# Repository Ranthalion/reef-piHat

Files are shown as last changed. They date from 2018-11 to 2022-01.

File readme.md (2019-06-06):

View this project on [CADLAB.io](https://cadlab.io/project/1832). 

# reef-piHat
RPI Hat for reef-pi

Supports
 - Back powering the rpi with 5v
 - 9 channels of PWM control via PCA9685 (split between 3 connectors)
 - 3 channels for 1 wire communication (up to 3 DS18B20 temperature probes)
 - 2 i2c ports for ph probe modules
 - 2 ATO sensors
 - 8 channel 12v relay control via ULN2803
 - 8 GPIO breakout (intended for 3.3v relay module)

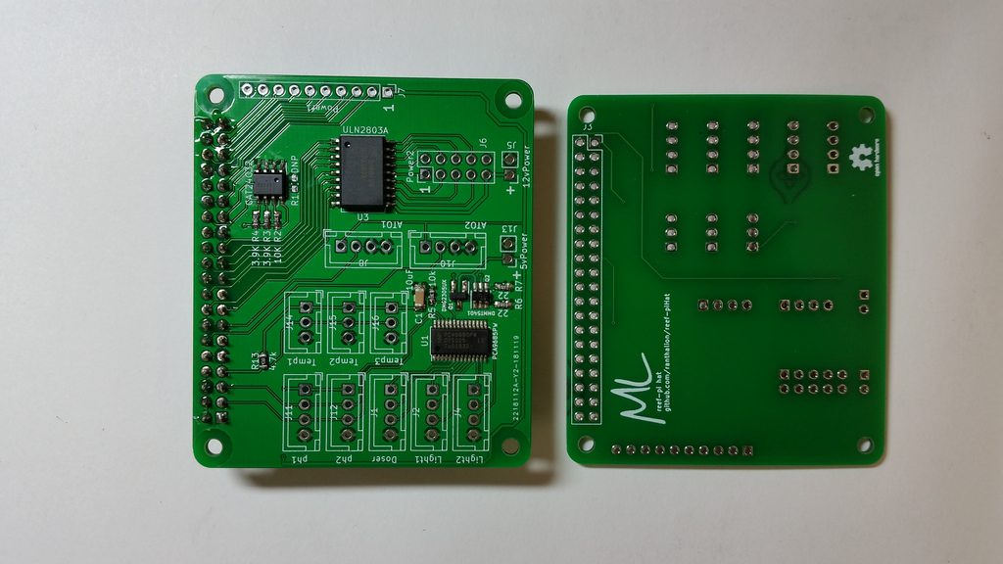
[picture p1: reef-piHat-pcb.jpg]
Board


Schematic

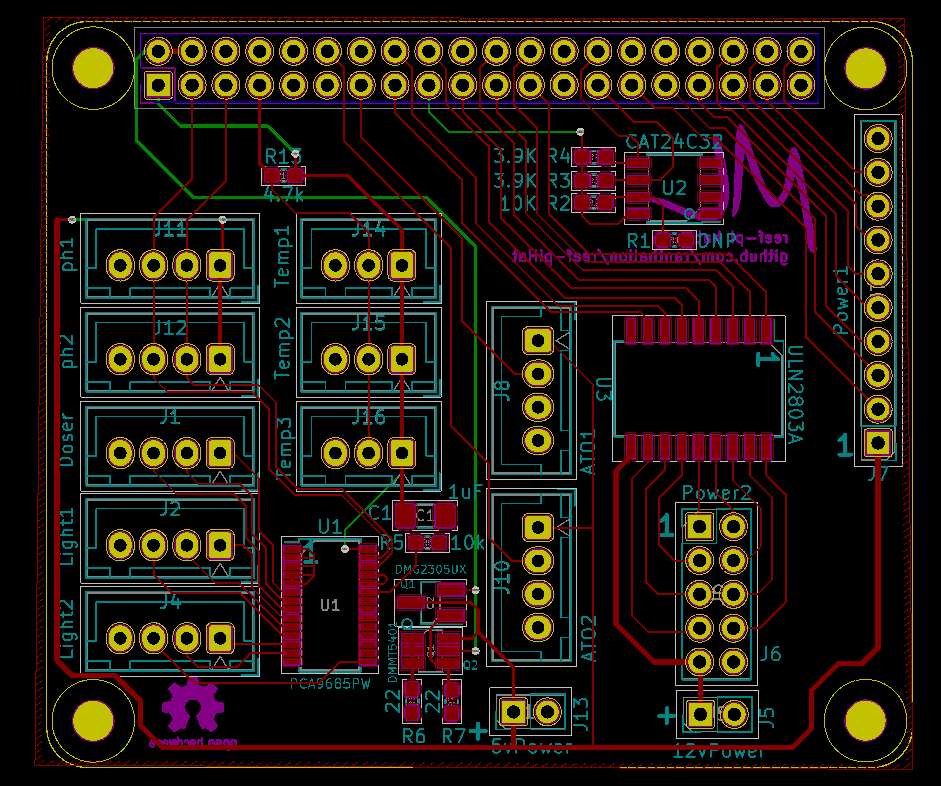
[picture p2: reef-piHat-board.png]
Layout




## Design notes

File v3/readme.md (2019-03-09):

# reef-piHat
RPI Hat for reef-pi

Supports
 - Back powering the rpi with 5v
 - 12 channels of PWM control via PCA9685 (split between 4 connectors) with address selection
 - 3 channels for 1 wire communication (up to 3 DS18B20 temperature probes)
 - 2 i2c ports for ph probe modules
 - 2 ATO sensors with input protection
 - 8 channel 12v relay control via ULN2803
 - 8 GPIO breakout with input and output protection

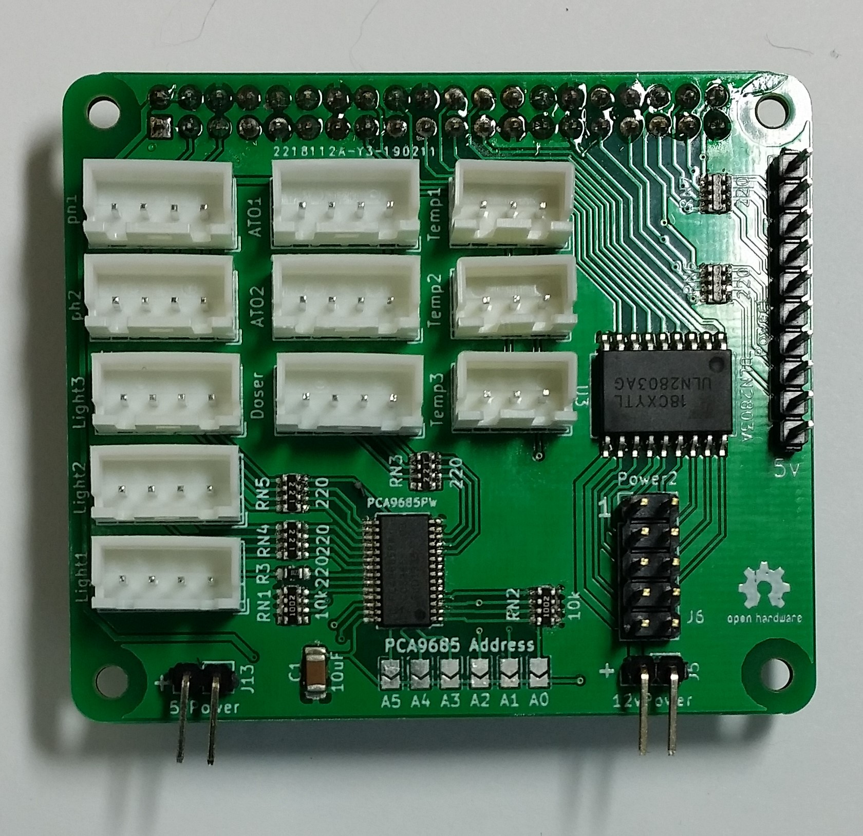
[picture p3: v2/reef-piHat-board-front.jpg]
Board front


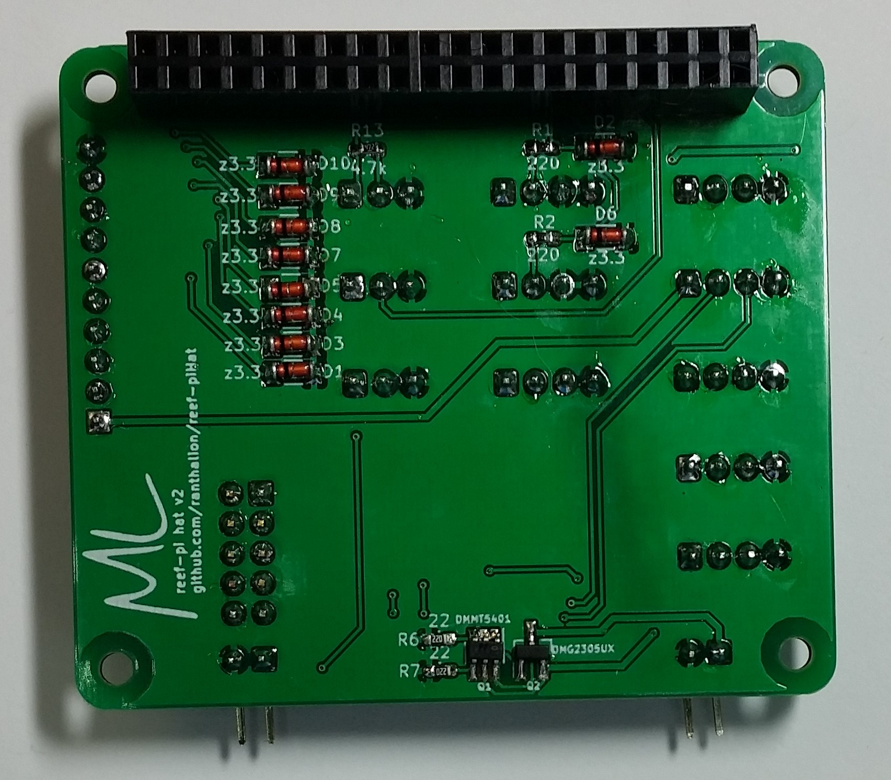
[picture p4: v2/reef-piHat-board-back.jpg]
Board back


Schematic

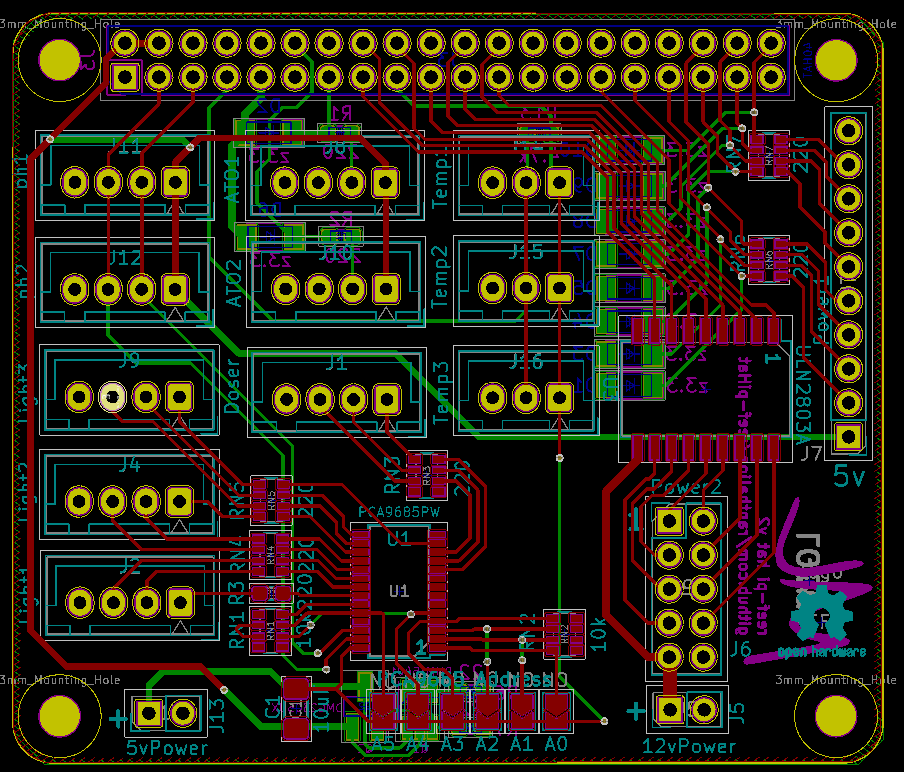
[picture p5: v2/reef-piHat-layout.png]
Layout




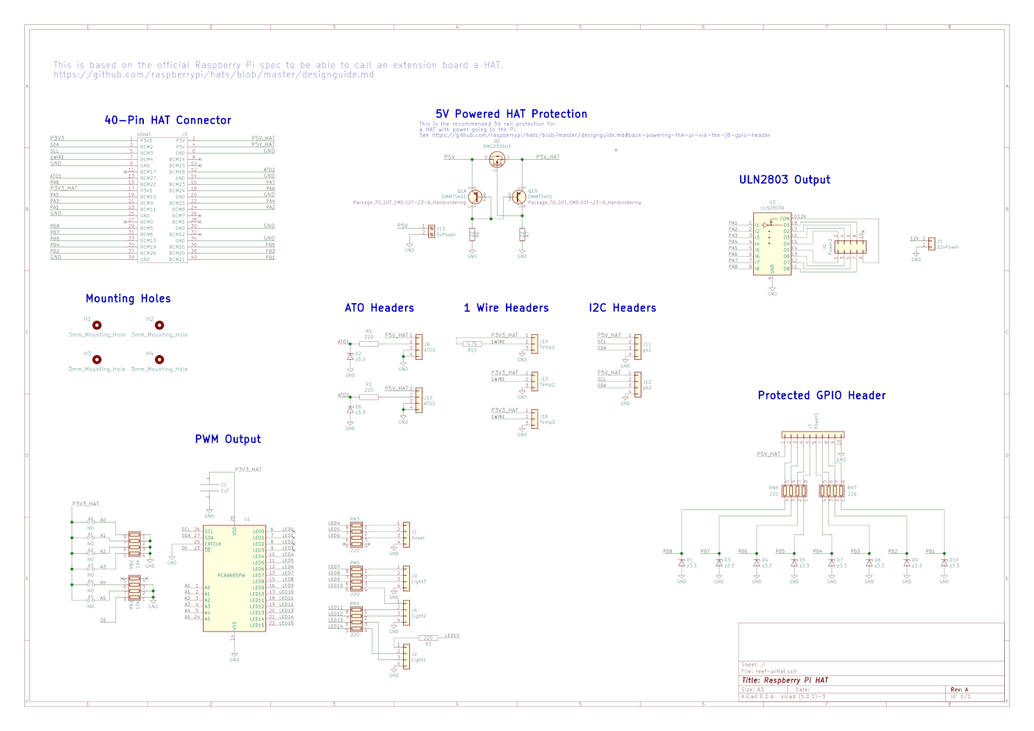
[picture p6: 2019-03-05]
v3/reef-piHat-schematic.png

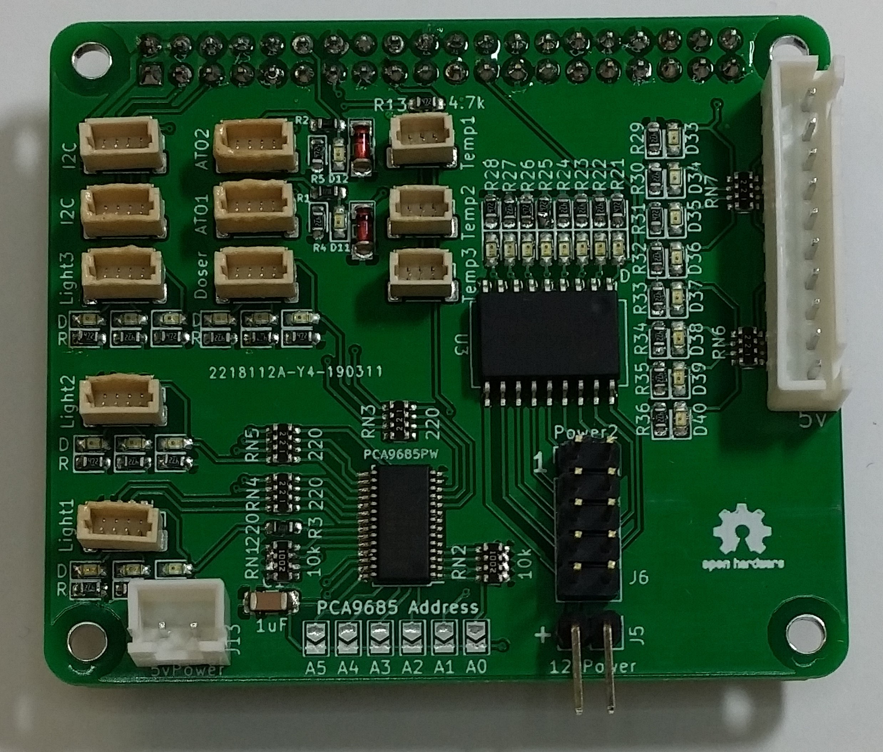
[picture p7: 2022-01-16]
v3/front.jpg

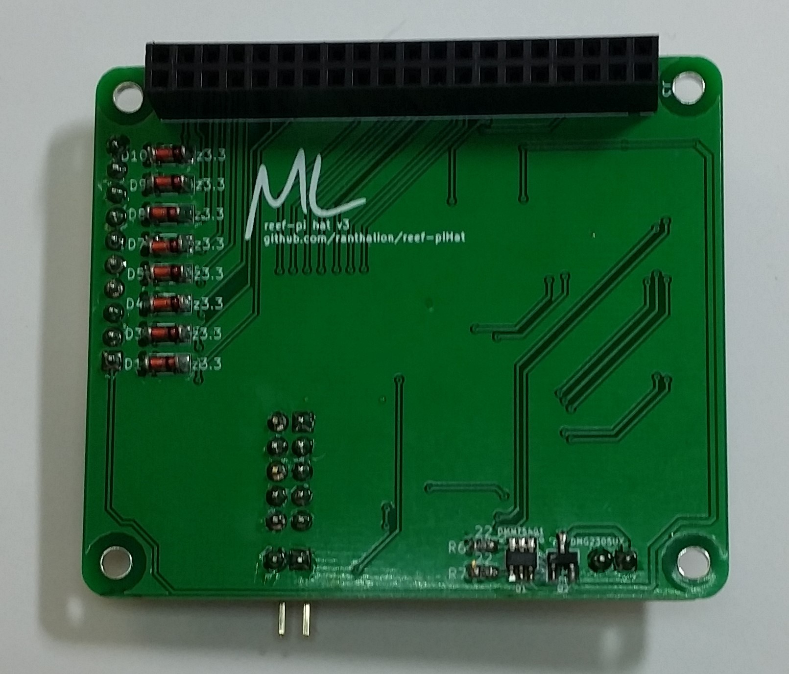
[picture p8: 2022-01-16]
v3/back.jpg

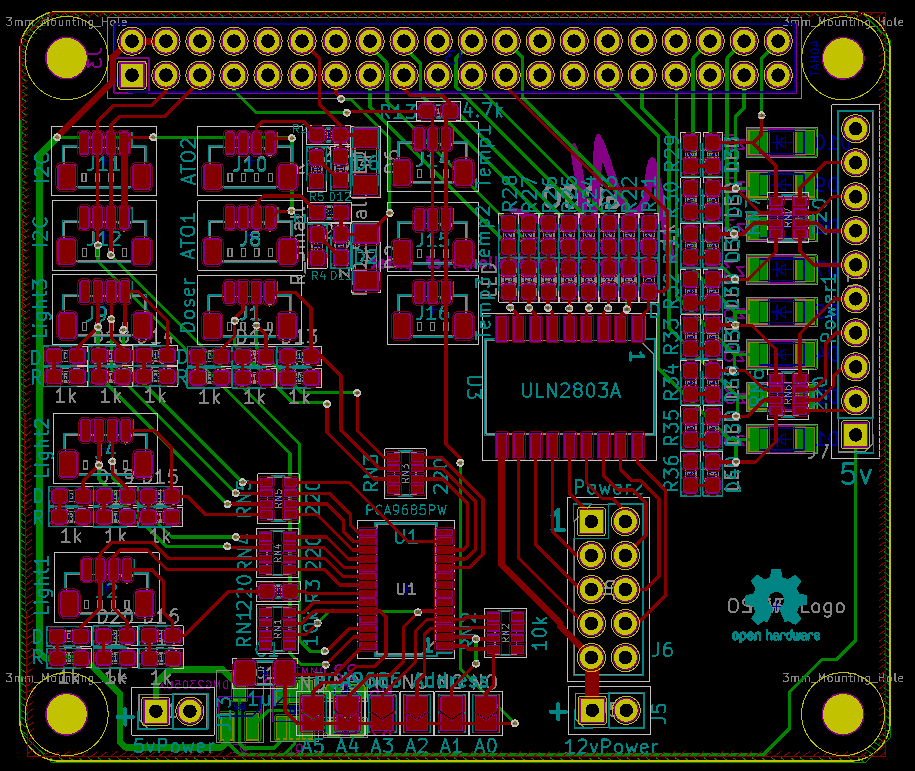
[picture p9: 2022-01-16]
v3/reef-piHat-board.png

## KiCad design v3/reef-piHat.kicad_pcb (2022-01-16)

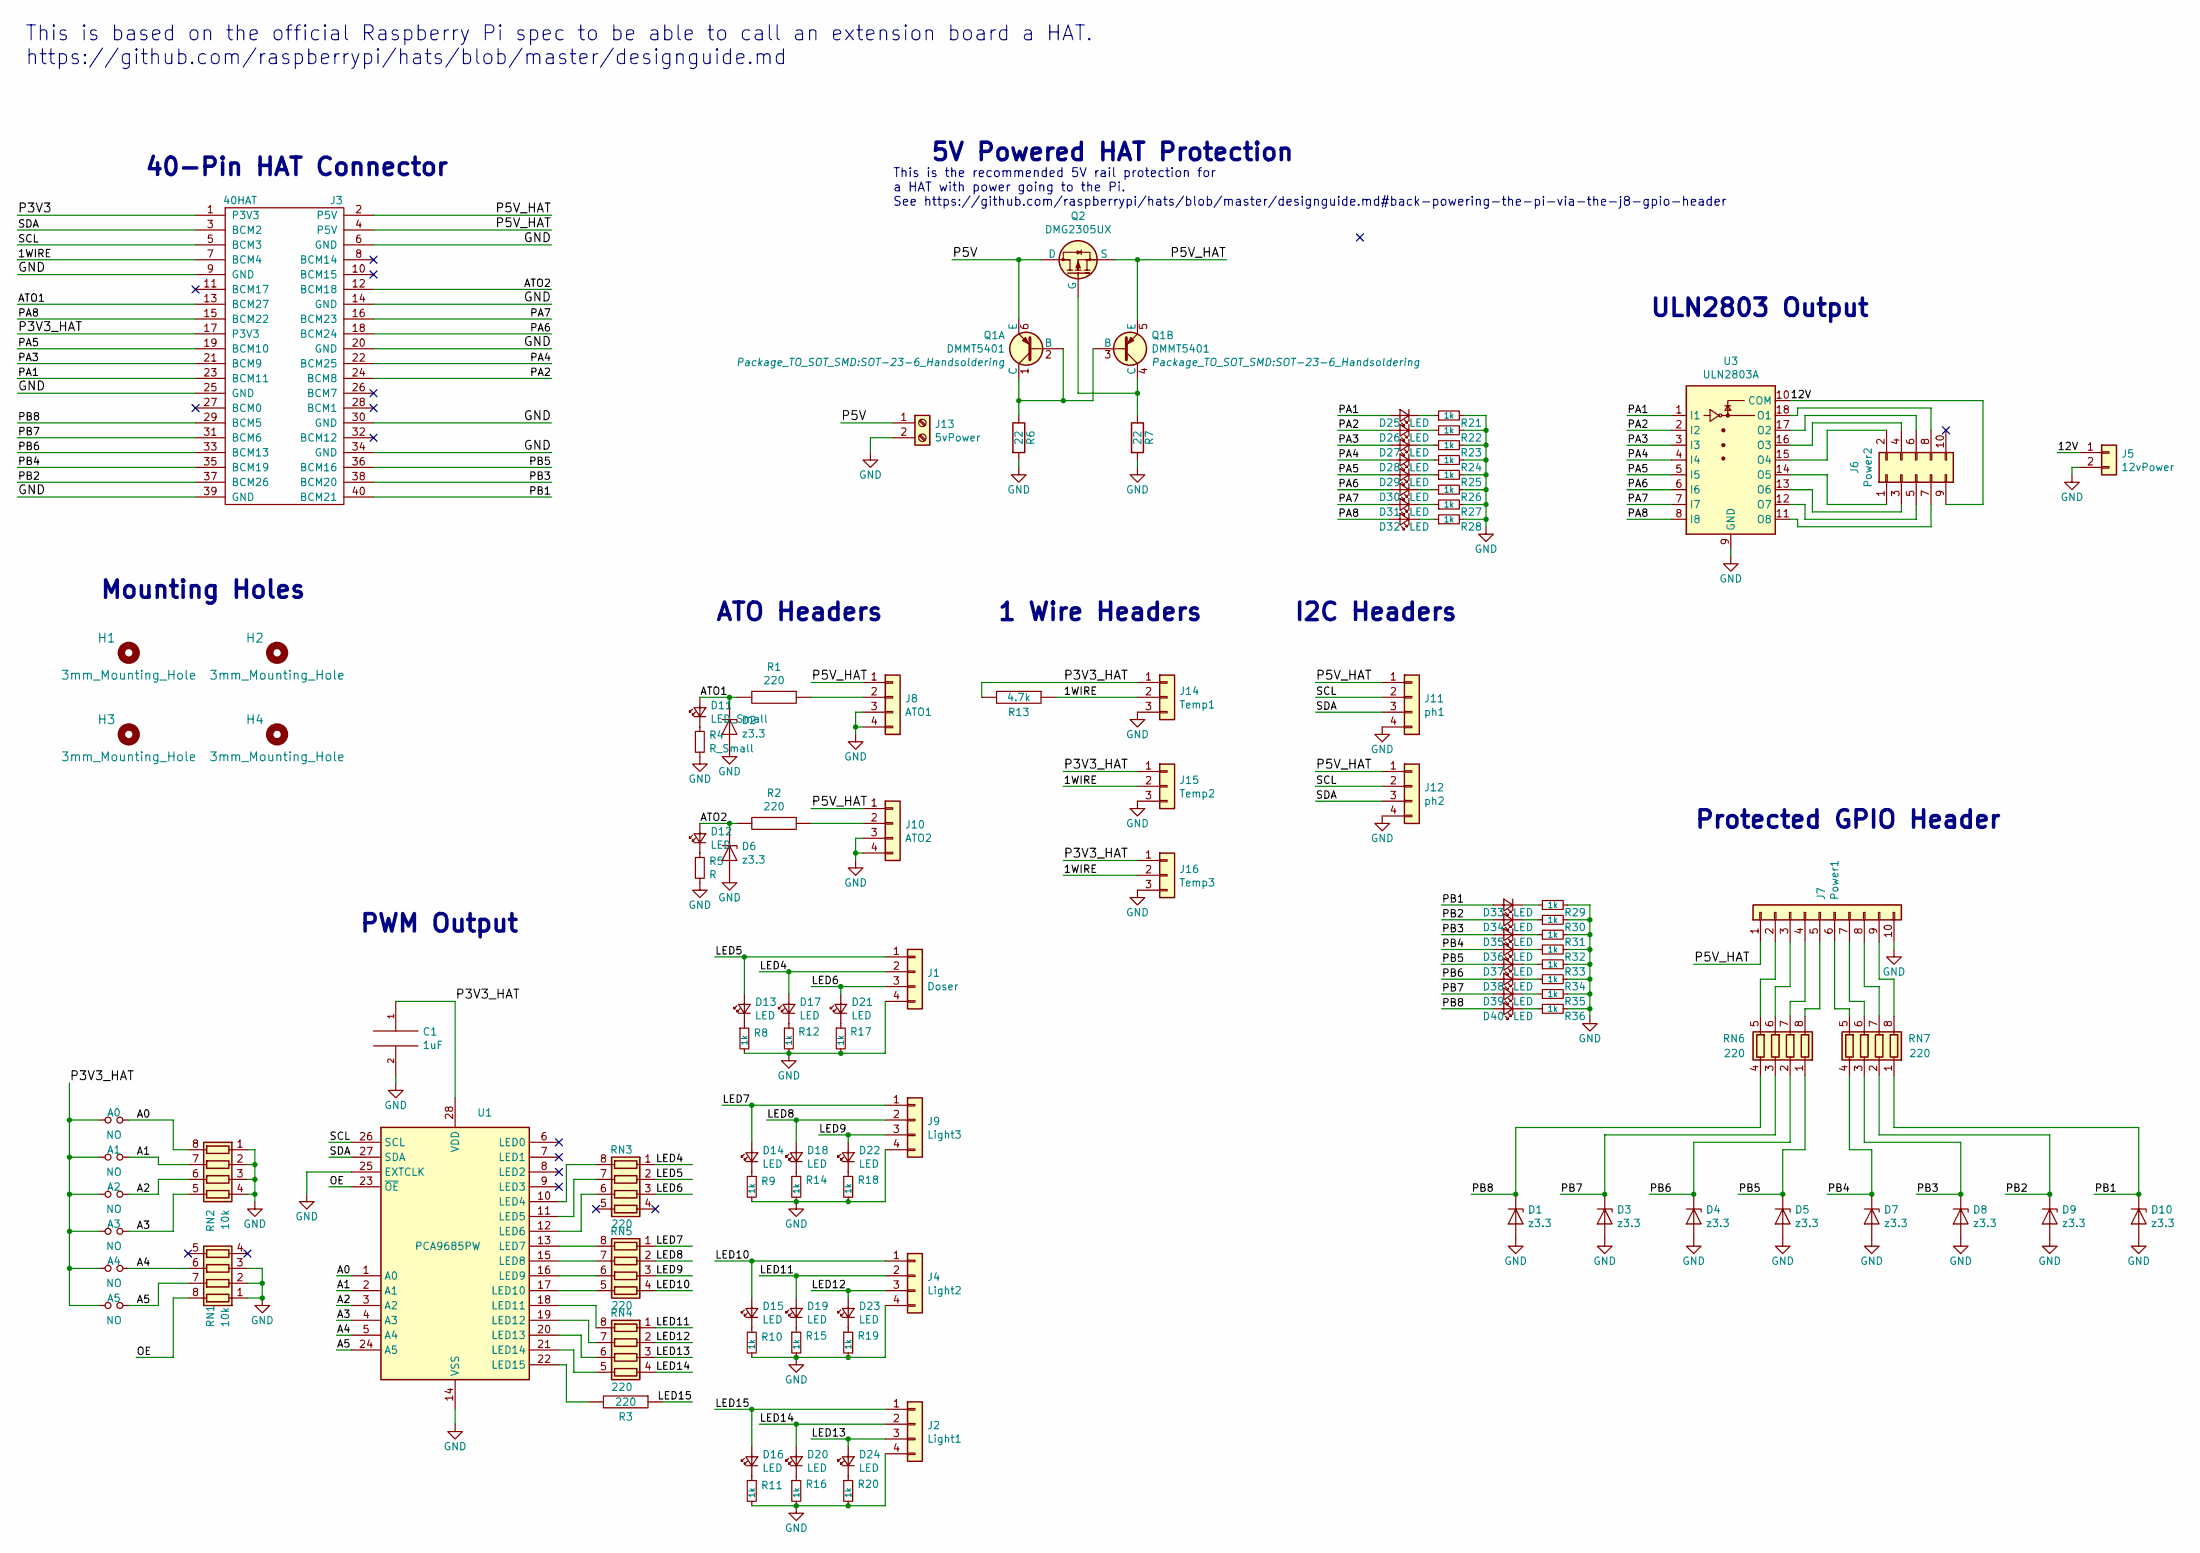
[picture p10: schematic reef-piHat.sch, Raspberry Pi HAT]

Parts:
A0, A1, A2, A3, A4, A5: NO; SolderJumper-2_P1.3mm_Open_TrianglePad1.0x1.5mm
C1: 1uF; C_1206_3216Metric_Pad1.42x1.75mm_HandSolder
D1, D2, D3, D4, D5, D6, D7, D8, D9, D10: z3.3; D_MiniMELF
D11: LED_Small; LED_0603_1608Metric_Pad1.05x0.95mm_HandSolder
D12, D13, D14, D15, D16, D17, D18, D19, D20, D21, D22, D23, D24, D25, D26, D27, D28, D29, D30, D31, D32, D33, D34, D35, D36, D37, D38, D39, D40: LED; LED_0603_1608Metric_Pad1.05x0.95mm_HandSolder
H1, H2, H3, H4: 3mm_Mounting_Hole; NPTH_3mm_ID
J1: Doser; JST_SH_BM04B-SRSS-TB_1x04-1MP_P1.00mm_Vertical
J2: Light1; JST_SH_BM04B-SRSS-TB_1x04-1MP_P1.00mm_Vertical
J3: 40HAT; PinSocket_2x20_P2.54mm_Vertical
J4: Light2; JST_SH_BM04B-SRSS-TB_1x04-1MP_P1.00mm_Vertical
J5: 12vPower; PinHeader_1x02_P2.54mm_Vertical
J6: Power2; PinHeader_2x05_P2.54mm_Vertical
J7: Power1; PinHeader_1x10_P2.54mm_Vertical
J8: ATO1; JST_SH_BM04B-SRSS-TB_1x04-1MP_P1.00mm_Vertical
J9: Light3; JST_SH_BM04B-SRSS-TB_1x04-1MP_P1.00mm_Vertical
J10: ATO2; JST_SH_BM04B-SRSS-TB_1x04-1MP_P1.00mm_Vertical
J11: ph1; JST_SH_BM04B-SRSS-TB_1x04-1MP_P1.00mm_Vertical
J12: ph2; JST_SH_BM04B-SRSS-TB_1x04-1MP_P1.00mm_Vertical
J13: 5vPower; PinHeader_1x02_P2.54mm_Vertical
J14: Temp1; JST_SH_BM03B-SRSS-TB_1x03-1MP_P1.00mm_Vertical
J15: Temp2; JST_SH_BM03B-SRSS-TB_1x03-1MP_P1.00mm_Vertical
J16: Temp3; JST_SH_BM03B-SRSS-TB_1x03-1MP_P1.00mm_Vertical
Q1: DMMT5401; SOT-23-6_Handsoldering
Q2: DMG2305UX; SOT-23_Handsoldering
R1, R2, R3: 220; R_0603_1608Metric_Pad1.05x0.95mm_HandSolder
R4: R_Small; LED_0603_1608Metric_Pad1.05x0.95mm_HandSolder
R5: R; LED_0603_1608Metric_Pad1.05x0.95mm_HandSolder
R6, R7: 22; R_0603_1608Metric_Pad1.05x0.95mm_HandSolder; MPN RC0402JR-0722RL
R8, R9, R10, R11, R12, R14, R15, R16, R17, R18, R19, R20, R21, R22, R23, R24, R25, R26, R27, R28, R29, R30, R31, R32, R33, R34, R35, R36: 1k; LED_0603_1608Metric_Pad1.05x0.95mm_HandSolder
R13: 4.7k; R_0603_1608Metric_Pad1.05x0.95mm_HandSolder
RN1, RN2: 10k; R_Array_Convex_4x0603
RN3, RN4, RN5, RN6, RN7: 220; R_Array_Convex_4x0603
U1: PCA9685PW; TSSOP-28_4.4x9.7mm_P0.65mm
U3: ULN2803A; SOP-18_7.0x12.5mm_P1.27mm

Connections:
/1WIRE: J3.7 (BCM4), J14.2, J15.2, J16.2, R13.1
/12V: J5.1, J6.9, U3.10 (COM)
/A0: A0.1, RN2.8 (R1.2), U1.1 (A0)
/A1: A1.1, RN2.7 (R2.2), U1.2 (A1)
/A2: A2.1, RN2.6 (R3.2), U1.3 (A2)
/A3: A3.1, RN2.5 (R4.2), U1.4 (A3)
/A4: A4.1, RN1.6 (R3.2), U1.5 (A4)
/A5: A5.1, RN1.7 (R2.2), U1.24 (A5)
/ATO1: D2.1 (K), D11.2 (A), J3.13 (BCM27), R1.2
/ATO2: D6.1 (K), D12.2 (A), J3.12 (BCM18), R2.2
/LED4: D17.2 (A), J1.2, RN3.1 (R1.1)
/LED5: D13.2 (A), J1.1, RN3.2 (R2.1)
/LED6: D21.2 (A), J1.3, RN3.3 (R3.1); also elsewhere on the board
/LED7: D14.2 (A), J9.1, RN5.1 (R1.1)
/LED8: D18.2 (A), J9.2, RN5.2 (R2.1)
/LED9: D22.2 (A), J9.3, RN5.3 (R3.1); also elsewhere on the board
/LED10: D15.2 (A), J4.1, RN5.4 (R4.1)
/LED11: D19.2 (A), J4.2, RN4.1 (R1.1)
/LED12: D23.2 (A), J4.3, RN4.2 (R2.1); also elsewhere on the board
/LED13: D24.2 (A), J2.3, RN4.3 (R3.1); also elsewhere on the board
/LED14: D20.2 (A), J2.2, RN4.4 (R4.1)
/LED15: D16.2 (A), J2.1, R3.1
/OE: RN1.8 (R1.2), U1.23 (~OE)
/P3V3: J3.1 (P3V3)
/P3V3_HAT: A0.2, A1.2, A2.2, A3.2, A4.2, A5.2, C1.1, J3.17 (P3V3), J14.1, J15.1, J16.1, R13.2, U1.28 (VDD)
/P5V: J13.1, Q1.6 (E), Q2.3 (D)
/P5V_HAT: J3.2 (P5V), J3.4 (P5V), J7.1, J8.1, J10.1, J11.1, J12.1, Q1.5 (E), Q2.2 (S)
/PA1: D25.2 (A), J3.23 (BCM11), U3.1 (I1); also elsewhere on the board
/PA2: D26.2 (A), J3.24 (BCM8), U3.2 (I2)
/PA3: D27.2 (A), J3.21 (BCM9), U3.3 (I3)
/PA4: D28.2 (A), J3.22 (BCM25), U3.4 (I4)
/PA5: D29.2 (A), J3.19 (BCM10), U3.5 (I5)
/PA6: D30.2 (A), J3.18 (BCM24), U3.6 (I6)
/PA7: D31.2 (A), J3.16 (BCM23), U3.7 (I7)
/PA8: D32.2 (A), J3.15 (BCM22), U3.8 (I8)
/PB1: D10.1 (K), D33.2 (A), J3.40 (BCM21), RN7.1 (R1.1)
/PB2: D9.1 (K), D34.2 (A), J3.37 (BCM26), RN7.2 (R2.1)
/PB3: D8.1 (K), D35.2 (A), J3.38 (BCM20), RN7.3 (R3.1)
/PB4: D7.1 (K), D36.2 (A), J3.35 (BCM19), RN7.4 (R4.1)
/PB5: D5.1 (K), D37.2 (A), J3.36 (BCM16), RN6.1 (R1.1)
/PB6: D4.1 (K), D38.2 (A), J3.33 (BCM13), RN6.2 (R2.1)
/PB7: D3.1 (K), D39.2 (A), J3.31 (BCM6), RN6.3 (R3.1)
/PB8: D1.1 (K), D40.2 (A), J3.29 (BCM5), RN6.4 (R4.1)
/SCL: J3.5 (BCM3), J11.2, J12.2, U1.26 (SCL)
/SDA: J3.3 (BCM2), J11.3, J12.3, U1.27 (SDA)
GND: C1.2, D1.2 (A), D2.2 (A), D3.2 (A), D4.2 (A), D5.2 (A), D6.2 (A), D7.2 (A), D8.2 (A), D9.2 (A), D10.2 (A), J1.4, J2.4, J3.6 (GND), J3.9 (GND), J3.14 (GND), J3.20 (GND), J3.25 (GND), J3.30 (GND), J3.34 (GND), J3.39 (GND), J4.4, J5.2, J7.10, J8.3, J8.4, J9.4, J10.3, J10.4, J11.4, J12.4, J13.2, J14.3, J15.3, J16.3, R4.2, R5.2, R6.2, R7.2, R8.2, R9.2, R10.2, R11.2, R12.2, R14.2, R15.2, R16.2, R17.2, R18.2, R19.2, R20.2, R21.2, R22.2, R23.2, R24.2, R25.2, R26.2, R27.2, R28.2, R29.2, R30.2, R31.2, R32.2, R33.2, R34.2, R35.2, R36.2, RN1.1 (R1.1), RN1.2 (R2.1), RN1.3 (R3.1), RN2.1 (R1.1), RN2.2 (R2.1), RN2.3 (R3.1), RN2.4 (R4.1), U1.14 (VSS), U1.25 (EXTCLK), U3.9 (GND); also elsewhere on the board
unnamed: D11.1 (K), R4.1
unnamed: D12.1 (K), R5.1
unnamed: D13.1 (K), R8.1
unnamed: D14.1 (K), R9.1
unnamed: D15.1 (K), R10.1
unnamed: D16.1 (K), R11.1
unnamed: D17.1 (K), R12.1
unnamed: D18.1 (K), R14.1
unnamed: D19.1 (K), R15.1
unnamed: D20.1 (K), R16.1
unnamed 56: D21.1 (K), R17.1; also elsewhere on the board
unnamed 57: D22.1 (K), R18.1; also elsewhere on the board
unnamed 58: D23.1 (K), R19.1; also elsewhere on the board
unnamed 59: D24.1 (K), R20.1; also elsewhere on the board
unnamed 60: D25.1 (K), R21.1; also elsewhere on the board
unnamed: D26.1 (K), R22.1
unnamed: D27.1 (K), R23.1
unnamed: D28.1 (K), R24.1
unnamed: D29.1 (K), R25.1
unnamed: D30.1 (K), R26.1
unnamed: D31.1 (K), R27.1
unnamed: D32.1 (K), R28.1
unnamed: D33.1 (K), R29.1
unnamed: D34.1 (K), R30.1
unnamed: D35.1 (K), R31.1
unnamed: D36.1 (K), R32.1
unnamed: D37.1 (K), R33.1
unnamed: D38.1 (K), R34.1
unnamed: D39.1 (K), R35.1
unnamed: D40.1 (K), R36.1
unnamed: J6.1, U3.14 (O5)
unnamed: J6.2, U3.15 (O4)
unnamed: J6.3, U3.13 (O6)
unnamed: J6.4, U3.16 (O3)
unnamed: J6.5, U3.12 (O7)
unnamed: J6.6, U3.17 (O2)
unnamed: J6.7, U3.11 (O8)
unnamed: J6.8, U3.18 (O1)
unnamed: J7.2, RN6.5 (R4.2)
unnamed: J7.3, RN6.6 (R3.2)
unnamed: J7.4, RN6.7 (R2.2)
unnamed: J7.5, RN6.8 (R1.2)
unnamed: J7.6, RN7.5 (R4.2)
unnamed: J7.7, RN7.6 (R3.2)
unnamed: J7.8, RN7.7 (R2.2)
unnamed: J7.9, RN7.8 (R1.2)
unnamed: J8.2, R1.1
unnamed: J10.2, R2.1
unnamed: Q1.1 (C), Q1.2 (B), Q1.3 (B), R6.1
unnamed: Q1.4 (C), Q2.1 (G), R7.1
unnamed: R3.2, U1.22 (LED15)
unnamed: RN3.6 (R3.2), U1.12 (LED6)
unnamed: RN3.7 (R2.2), U1.11 (LED5)
unnamed: RN3.8 (R1.2), U1.10 (LED4)
unnamed: RN4.5 (R4.2), U1.21 (LED14)
unnamed: RN4.6 (R3.2), U1.20 (LED13)
unnamed: RN4.7 (R2.2), U1.19 (LED12)
unnamed: RN4.8 (R1.2), U1.18 (LED11)
unnamed: RN5.5 (R4.2), U1.17 (LED10)
unnamed: RN5.6 (R3.2), U1.16 (LED9)
unnamed: RN5.7 (R2.2), U1.15 (LED8)
unnamed: RN5.8 (R1.2), U1.13 (LED7)

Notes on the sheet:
PWM Output
40-Pin HAT Connector
This is based on the official Raspberry Pi spec to be able to call an extension board a HAT. https://github.com/raspberrypi/hats/blob/master/designguide.md
5V Powered HAT Protection
This is the recommended 5V rail protection for a HAT with power going to the Pi. See https://github.com/raspberrypi/hats/blob/master/designguide.md#back-powering-the-pi-via-the-j8-gpio-header
Mounting Holes
ULN2803 Output
ATO Headers
1 Wire Headers
I2C Headers
Protected GPIO Header

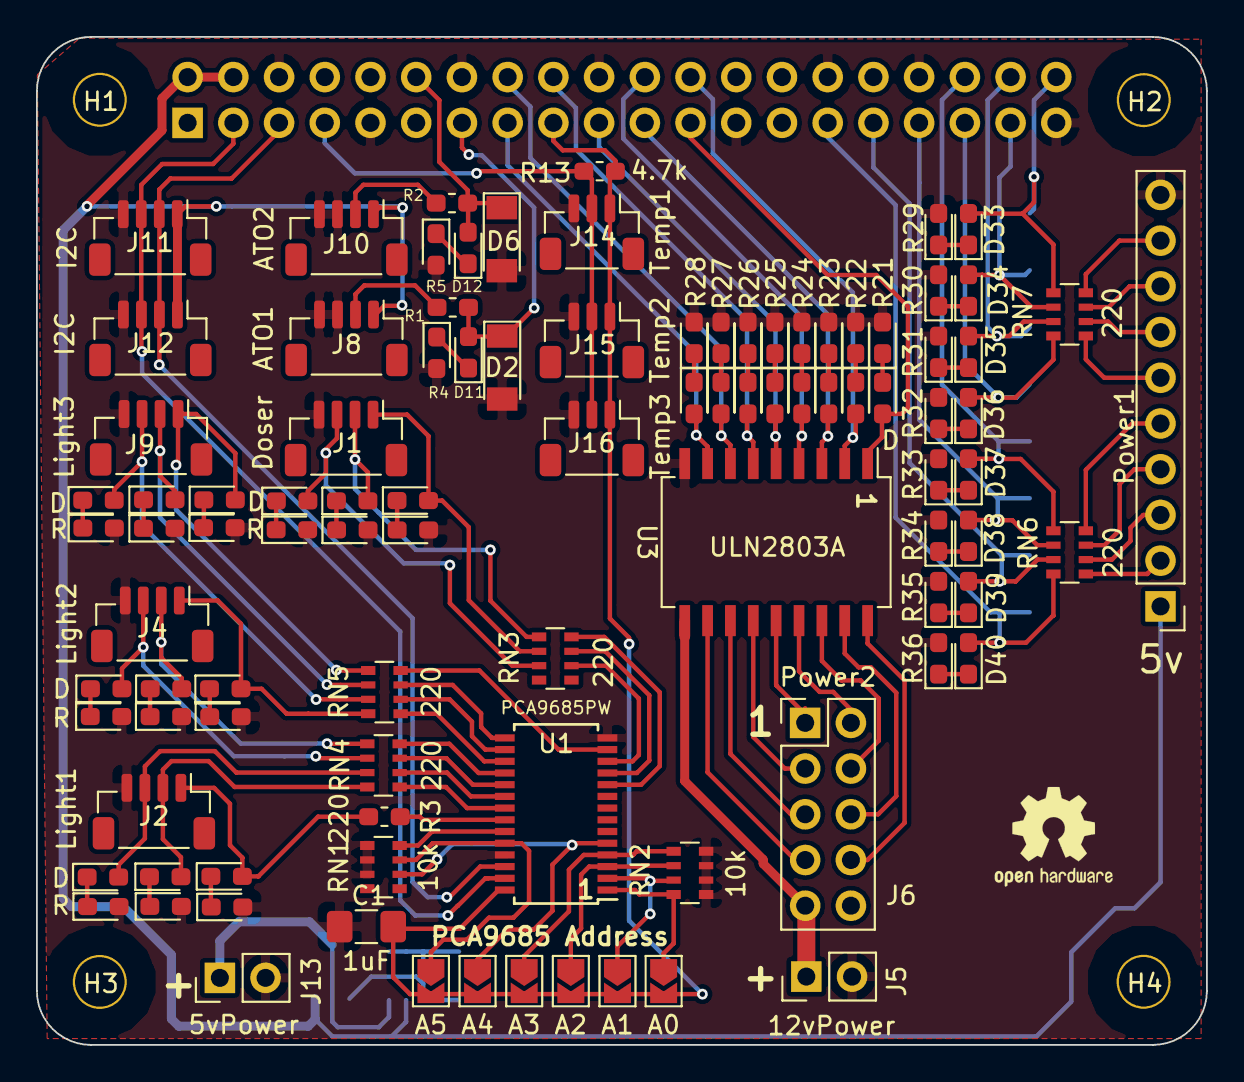
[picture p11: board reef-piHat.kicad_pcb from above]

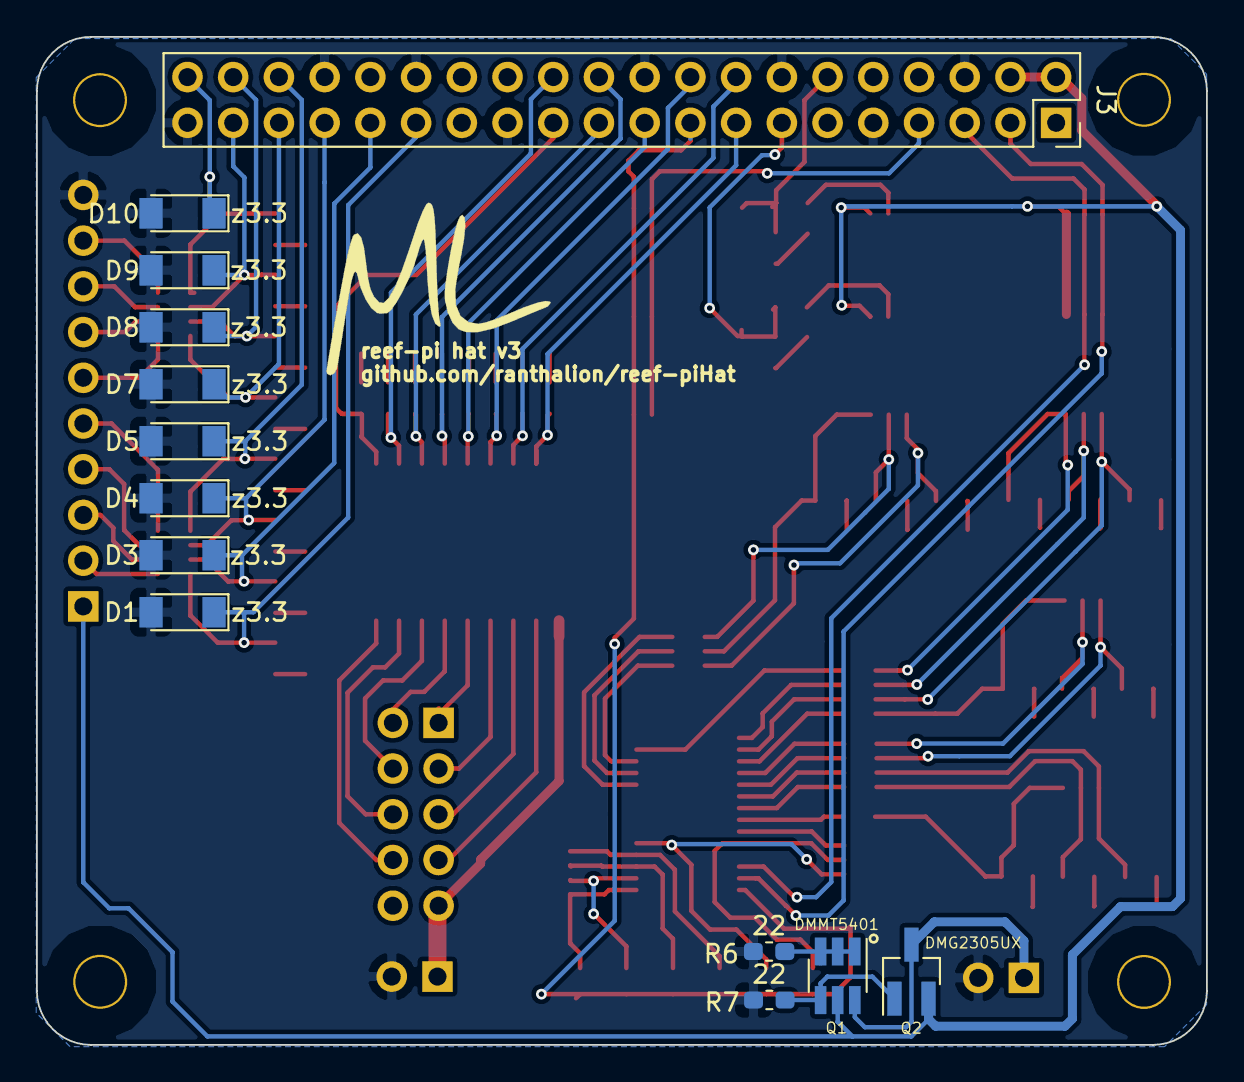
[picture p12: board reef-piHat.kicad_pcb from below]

Board: 2 copper layers, 65.0 x 56.0 mm, 114 parts (13 on the bottom side), 107 nets.

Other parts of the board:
D: LED; LED_0603_1608Metric_Pad1.05x0.95mm_HandSolder
D#2, D#3, D#4, D#5: LED; LED_0603_1608Metric_Pad1.05x0.95mm_HandSolder
R: 1k; LED_0603_1608Metric_Pad1.05x0.95mm_HandSolder
R#2, R#3, R#4: 1k; LED_0603_1608Metric_Pad1.05x0.95mm_HandSolder

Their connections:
/LED6: D.2; also elsewhere on the board
/LED9: D#2.2; also elsewhere on the board
/LED12: D#3.2; also elsewhere on the board
/LED13: D#4.2; also elsewhere on the board
/PA1: D#5.2; also elsewhere on the board
GND: R.2, R#2.2, R#3.2, R#4.2; also elsewhere on the board
unnamed 56: D.1, R.1; also elsewhere on the board
unnamed 57: D#2.1, R#2.1; also elsewhere on the board
unnamed 58: D#3.1, R#3.1; also elsewhere on the board
unnamed 59: D#4.1, R#4.1; also elsewhere on the board
unnamed 60: D#5.1; also elsewhere on the board

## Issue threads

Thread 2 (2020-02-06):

Recommended power source & connectors?

inktomi, 2020-02-06:
Hi - Do you have a recommended power source, or a document outlining the specific connectors to purchase? Maybe Mouser/etc links? It'd be really helpful - maybe you could add this to the Wiki here on Github?

Ranthalion, 2020-02-07:
Thanks for reaching out.
I took some notes on setting up the ADJ power strip [here](https://docs.google.com/document/d/1-2QfairnlTG81LUcIelvhvydTT4B78h4ATd5UrYzXdM/edit).  Amazon links for these kinds of things don't seem to be stable, but there are some notes showing alternates.

I noticed some images aren't displaying either.  I think it's a good idea to add some recommendations in the readme.  I'll pull some links together on my next update.

5V Power Supply (5 - 10 amps)
[Mouser](https://www.mouser.com/ProductDetail/MEAN-WELL/LRS-50-5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)
JST-XH connectors
2, 3, and 4 pin ([4 pin example on Amazon](https://www.amazon.com/Onkuey-Battery-Balance-Charger-Connector/dp/B01EVINNBE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))

Let me know if you have any specific questions about a component.  I'm glad to help.

inktomi, 2020-02-07:
Thank you! I think this would be a great addition to the README or the wiki here. This was exactly the info I needed. The one final question I've got is - to drive something like the Kessil lights - the "LIGHT" outputs - what voltage/etc are those giving? I want to drive something like the Kessil lights, but need a 12V PWM signal to drive the dimming.

Ranthalion, 2020-02-07:
The pwm output is 3.3v.  That driver states it can work with pwm or analog, but has a minimum requirement of 8%.

There are a handful of ways to bump it up to a higher voltage. It ranges from a single transistor to an op amp to a pcb module.

inktomi, 2020-02-07:
Ok, good to know. Working from a 3.3v signal I can figure out a way to convert it to 10V I'm sure. Thank you very much!

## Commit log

2018-11-18 Schematic and PCB for reef-pi hat
    [reef-piHat-B.Cu.gbr, reef-piHat-B.Mask.gbr, reef-piHat-B.SilkS.gbr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]
2018-11-21 Complete layout and update gerbers
    [reef-piHat-B.Cu.gbr, reef-piHat-B.Fab.gbr, reef-piHat-B.Mask.gbr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]
2018-11-25 Add readme and images
    [reef-piHat.kicad_pcb, reef-piHat.sch]
2019-01-31 Initial v2 commit
    [reef-piHat-B.Cu.gbr, reef-piHat-B.Fab.gbr, reef-piHat-B.Mask.gbr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]
2019-02-10 v2 design
    [reef-piHat.kicad_pcb, reef-piHat.sch]
2019-02-15 update images
    [reef-piHat.kicad_pcb, reef-piHat.sch]
2019-03-05 v3 schematic and layout
    [reef-piHat-B.Cu.gbr, reef-piHat-B.Mask.gbr, reef-piHat-B.SilkS.gbr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]
2019-03-09 add v3 gerbers
    [reef-piHat-B.Cu.gbr, reef-piHat-B.Mask.gbr, reef-piHat-B.SilkS.gbr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]
2022-01-16 Update gerbers
    [_saved_reef-piHat.sch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]
